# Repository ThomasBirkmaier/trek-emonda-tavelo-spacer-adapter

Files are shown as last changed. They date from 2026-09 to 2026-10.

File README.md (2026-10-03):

# Trek Émonda × Tavelo Avro Rise – Spacer-Adapter

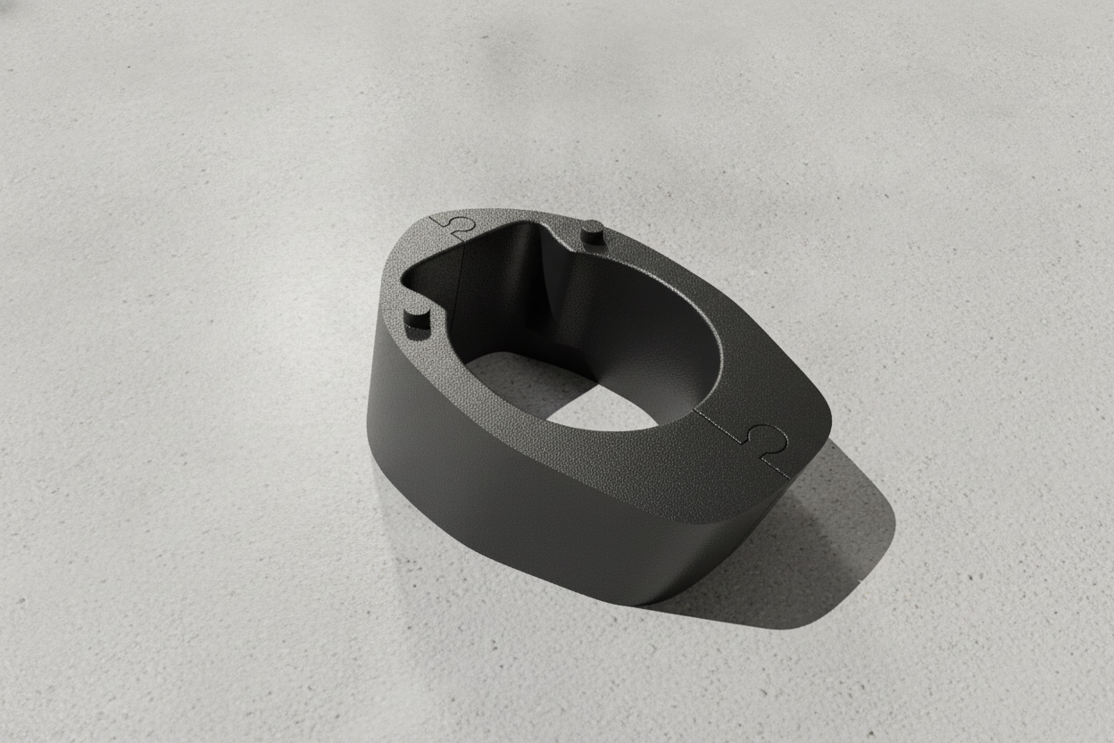
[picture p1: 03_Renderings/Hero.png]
Adapter, zusammengesetzt (generierte Darstellung, Variante Stift)


Zweiteiliger, 3D-gedruckter Adapter, mit dem ein integriertes **Tavelo Avro Rise**-Cockpit auf einem **Trek Émonda SL 6 (2024)** sitzt. Der originale Trek-Steuersatzdeckel bleibt unverändert, die Bremsleitungen laufen innen, und die Hydraulik muss nicht geöffnet werden.

Das Modell ist parametrisch (Python/CadQuery). Wer einen anderen Rahmen oder andere Winkel hat, ändert ein paar Zahlen und exportiert neu.

**Stand (Rev. D.1, 2026-10-03):** Geometrie abgeschlossen für die Bezugshöhe 22 mm (unverändert seit Rev. D), Festigkeit mit FEM abgeschätzt. Drei Prototypen wurden gedruckt und am Rad geprüft; der dritte (Variante Passstift, PETG-HF) passt ohne weitere Korrektur. Für den Dauerbetrieb empfohlen bleibt PA12 (MJF), siehe [Drucken](#drucken). Befunde, Entscheidungen und offene Punkte: [`KONSTRUKTION.md`](KONSTRUKTION.md).

## Für welches Rad und welches Cockpit

Konstruiert und vermessen an genau dieser Kombination:

| | |
|---|---|
| Rahmen | **Trek Émonda SL 6, Modelljahr 2024** (Gen-3-Plattform), 500 Series OCLV Carbon (**SL, nicht SLR**), Größe 54 |
| Artikel | GTIN/EAN 768682472743, Trek-Teilenr. 5297498 |
| Steuersatz | originaler Trek-Steuersatzdeckel mit zwei Nasen hinten, bleibt montiert |
| Gabelschaft | Carbon, Ø 28,6, seitlich abgeflacht auf 26,75 |
| Schaltung | **105 Di2** (funkend): durch den Adapter laufen nur zwei Bremsleitungen, keine Schaltzüge |
| Cockpit | **Tavelo Avro Rise**, 380 mm Breite, 80 mm Länge, −10° |

Nicht geprüft, aber naheliegend:
- **Andere Größen des Émonda SL:** Der Deckel ist vermutlich gleich, der Trek-Winkel kann aber vom Lenkwinkel der Größe abhängen (siehe [An ein anderes Rad anpassen](#an-ein-anderes-rad-anpassen)).
- **Andere Breiten und Längen des Avro Rise:** Die Sitzfläche des Vorbaus sollte gleich sein, das ist aber nicht nachgemessen.
- **Émonda SLR, ältere Modelljahre, andere Tavelo-Modelle, mechanische Schaltungen:** nicht kompatibel bzw. ungeprüft. Maße und Winkel stehen in [`KONSTRUKTION.md`](KONSTRUKTION.md), das Modell lässt sich anpassen.

## Variante wählen

Es gibt zwei Varianten. Sie sind bis auf die beiden Stifte oben, die in die Sacklöcher des Vorbaus greifen, identisch.

| | **Passstift** (empfohlen) | **Stift** |
|---|---|---|
| Stifte oben | Zylinderstifte aus Edelstahl, eingeklebt | angedruckt, Ø 3 × 1,85 |
| Am Rad geprüft | Prototyp 3 | Prototyp 1 und 2 (Stifte passten) |
| Druckdatei | [`02_CAD/out/Passstift/`](02_CAD/out/Passstift) | [`02_CAD/out/Stift/`](02_CAD/out/Stift) |
| Zusätzlich nötig | 2 × Zylinderstift ISO 2338 Ø 3 m6 × 8, Edelstahl A2/A4; Klebstoff (2K-Epoxid oder Cyanacrylat) | nichts |
| Eigenschaften | Stahlstift belastbarer als ein gedruckter; Stift sitzt auf dem Lochgrund, die Lochtiefe (6,15) legt den Überstand 1,85 fest | keine Zukaufteile; bei FDM liegt am Fuß des Stifts eine Schichtgrenze |

| Passstift | Stift |
|---|---|
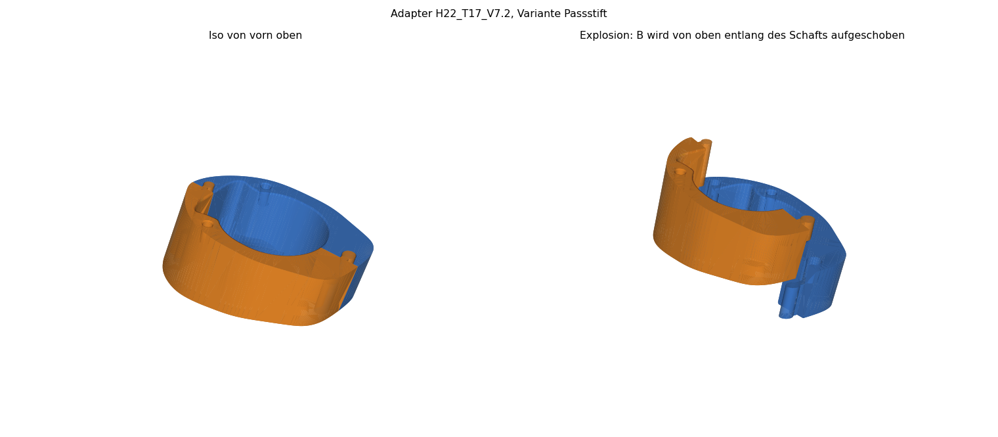
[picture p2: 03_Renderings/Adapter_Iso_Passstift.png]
Variante Passstift
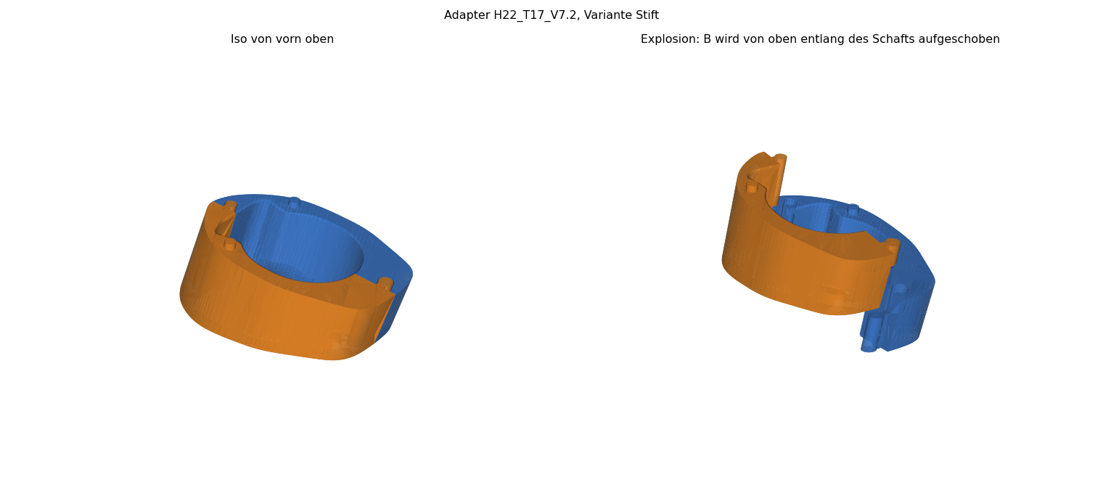
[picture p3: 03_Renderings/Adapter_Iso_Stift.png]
Variante Stift
|  |  |

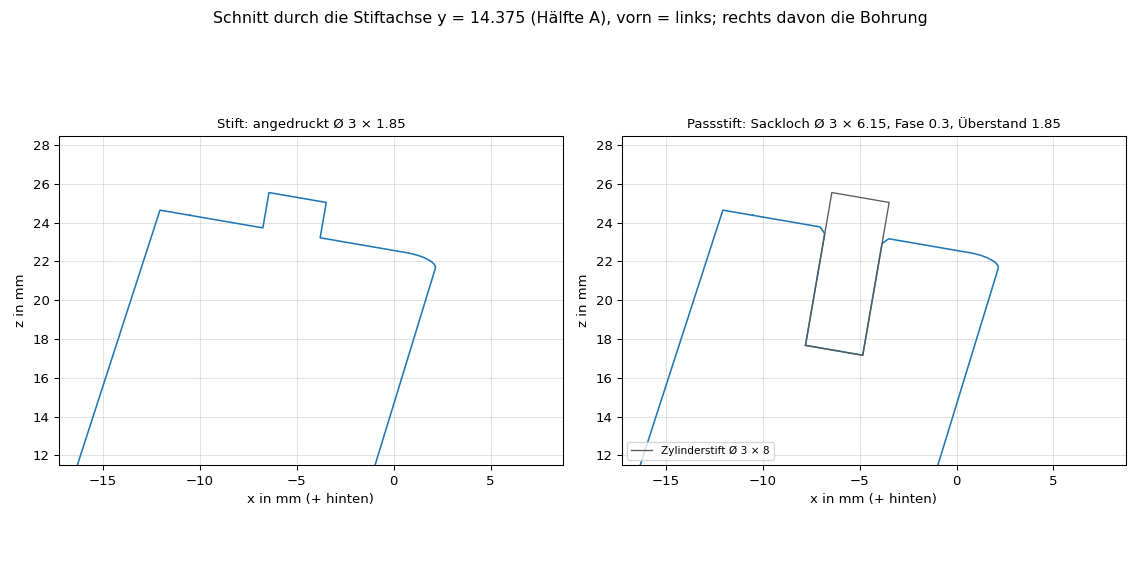
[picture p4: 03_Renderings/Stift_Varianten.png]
Schnitt durch die Stiftachse, beide Varianten


## Auf einen Blick

| | |
|---|---|
| Unterseite | passt auf den Trek-Deckel: Neigung α_T = 17°, zwei Nasen greifen in Taschen |
| Oberseite | passt unter den Tavelo-Vorbau: Neigung α_V ≈ 7,2° (gemessen 8°, am Prototyp 2 korrigiert), zwei Stifte Ø 3 × 1,85 greifen in die Sacklöcher |
| Keil | ≈ 9,8°, hinten dünn, vorn dick (auf einer ebenen Fläche: Hinterkante 16,3 mm, Spitze 26,2 mm hoch) |
| Höhe | 22 mm entlang der Schaftachse als Bezug (rechnerisch 22,4 mm am Durchstoßpunkt der Achse, siehe `KONSTRUKTION.md`, D-6) |
| Schaft | Ø 28,6 (seitlich abgeflacht auf 26,75), Bohrung Ø 30 als Langloch 2 mm nach hinten (32 × 30): Die Lage kommt von Nasen und Stiften, nicht vom Schaft |
| Leitungen | Kanal vor dem Schaft für zwei Bremsleitungen; unten seitlich angeschrägt, weil die hintere Leitung seitlich aus dem Trek-Deckel kommt |
| Teilung | zwei Hälften mit Gelenk nach Tavelo-Vorbild, werden entlang des Schafts zusammengeschoben |
| Kanten | innere Kanten an Ober- und Unterseite R 0,5, Übergang Bohrung → Leitungskanal R 2 |
| Werkstoff | empfohlen PA12, MJF-Druck; Prototyp 3 aus PETG-HF |
| Festigkeit | im Normalfall rund 4-fache Reserve in PETG-HF bei 3 kN entlang der Achse (lineare FEM-Abschätzung), siehe [Festigkeit](#festigkeit) |

## Festigkeit

Eine lineare FEM-Rechnung (gmsh + CalculiX, [`02_CAD/fem_adapter.py`](02_CAD/fem_adapter.py)) schätzt die Festigkeit unter einer Kraft von 3 kN entlang der Schaftachse ab. Das ist ein bewusst hoher Hüllwert; die Vorspannung allein liegt eher bei 0,3–1 kN.

- **Normalfall:** Reibung an Ober- und Unterseite hält den Keil. Größte Zugspannung 9 MPa, rund 4-fache Reserve in PETG-HF, knapp 6-fach in PA12; Verformung 0,06 mm.
- **Ohne Reibung** (gefettete Flächen) müssen Nasen oder Stifte die Keilkraft tragen, ≈ 17 % der Normalkraft. Dann werden Nasentasche und Lochmündung örtlich hoch belastet, und der angedruckte Stift der Variante Stift würde schon bei etwa 1 kN abscheren. Deshalb: Auflageflächen trocken und fettfrei, Variante Passstift.
- **Langzeit:** In PETG-HF kann der Spacer unter der Vorspannung bei Wärme kriechen; die Vorspannung lässt dann nach. Steuersatzspiel anfangs häufig prüfen, für den Dauerbetrieb PA12.

| Normalfall (Reibung trägt) | Grenzfall ohne Reibung, Passstift kippt im Vorbau |
|---|---|
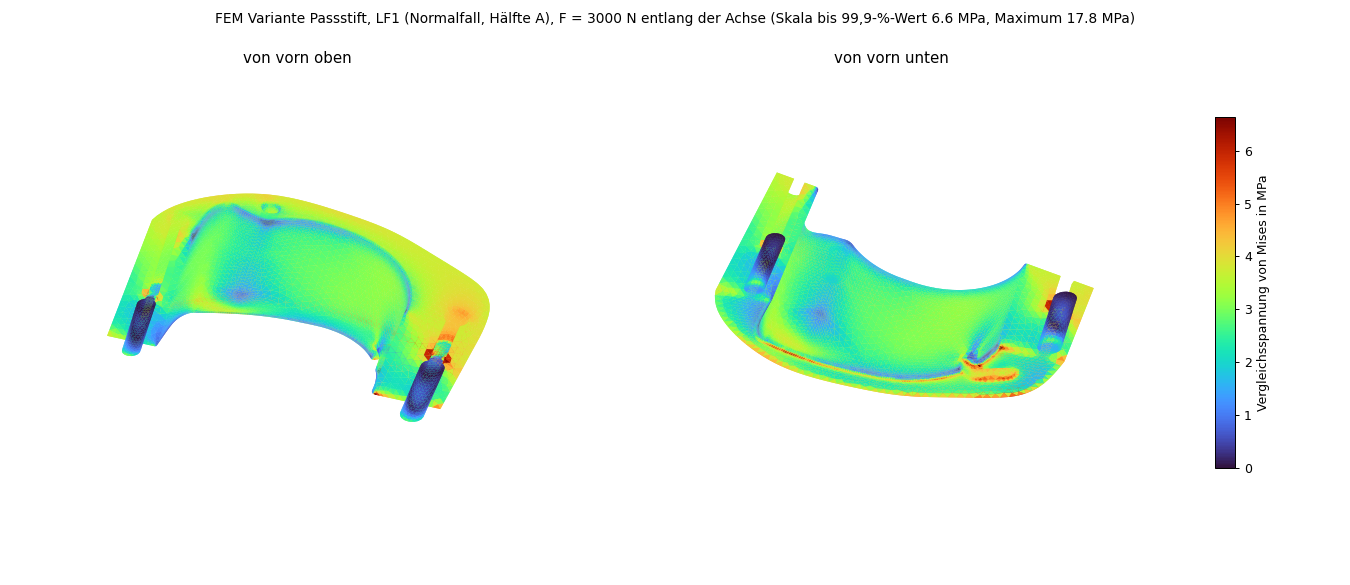
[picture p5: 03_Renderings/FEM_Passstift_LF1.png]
FEM Normalfall
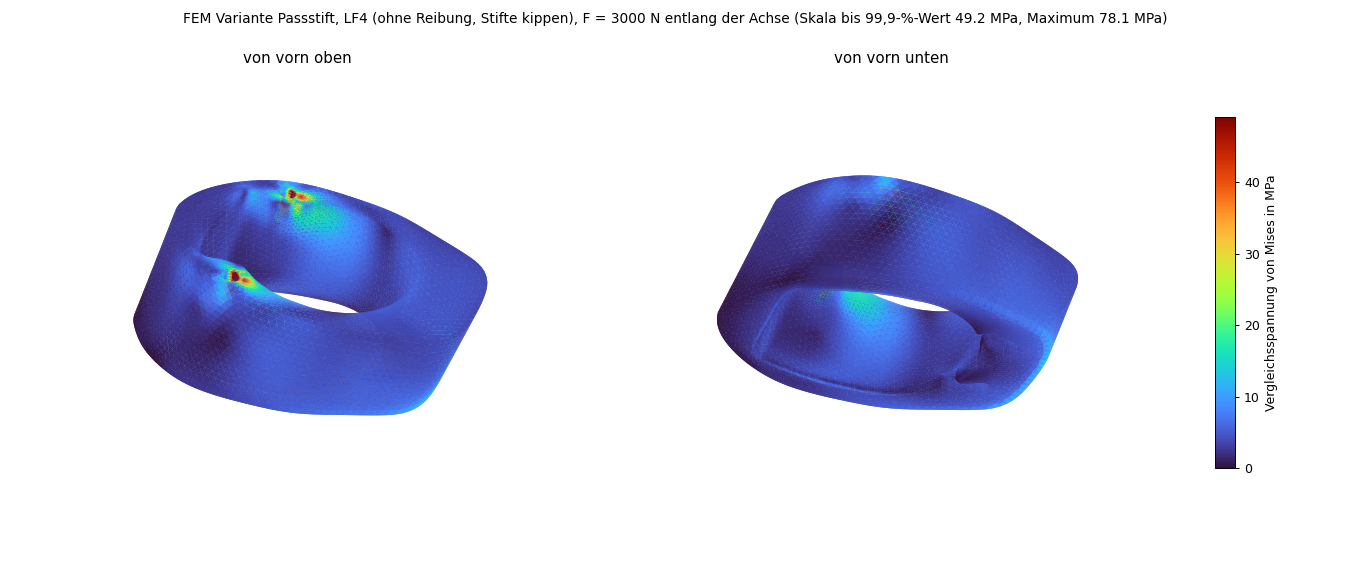
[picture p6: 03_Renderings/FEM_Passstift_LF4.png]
FEM ohne Reibung, Passstift
|  |  |

Das ist eine Abschätzung unter angenommenen Lasten, kein Festigkeitsnachweis. Modell, alle Lastfälle und Grenzen der Aussage: [`KONSTRUKTION.md`, Abschnitt 9](KONSTRUKTION.md#9-festigkeitsabschätzung-fem).

## Drucken

Am einfachsten lädt man unter [Releases](https://github.com/ThomasBirkmaier/trek-emonda-tavelo-spacer-adapter/releases) das ZIP der gewünschten Variante. Die Druckdatei `DRUCK_Adapter_H22_T17_V7.2_<Variante>` (`.stl`, `.3mf` oder `.step`) enthält beide Hälften, getrennt gelegt, Unterseite auf dem Druckbett. Bei einem Druckdienst (zum Beispiel Craftcloud) ist die Menge daher 1.

- **Verfahren und Werkstoff:** Für den Fahrbetrieb wird PA12 (MJF) empfohlen: Das Teil liegt in der Kraftkette der Lagervorspannung und wird warm. PETG (auch PETG-HF) kann unter dieser Last kriechen; wer es fährt, sollte das Steuersatzspiel anfangs häufig prüfen. Kein PLA. Für eine Passprobe reicht FDM.
- **Passungen:** Bohrung Ø 30 (0,7 mm Spiel radial zum Schaft, 2 mm Langloch nach hinten), Gelenk 0,2 mm Spiel radial, Nasentaschen 0,55 mm pro Seite quer und 0,3 mm längs, 3 mm tief. Sackloch der Variante Passstift Ø 3,0 × 6,15 mit Fase 0,3 (`PINHOLE_D` lässt sich an das Druckverfahren anpassen).
- **Dateinamen:** Bezugshöhe, Winkel und Variante stehen im Namen (`_H22_T17_V7.2_Passstift`). `Adapter_*` ist der zusammengebaute Zustand zur Ansicht, `DRUCK_*` die Druckdatei.

## Modell anpassen

Voraussetzung: Python 3.10–3.12 (getestet mit 3.11, Versionen in [`requirements.txt`](requirements.txt)).

```bash
git clone https://github.com/ThomasBirkmaier/trek-emonda-tavelo-spacer-adapter.git
cd trek-emonda-tavelo-spacer-adapter
python -m venv .venv && source .venv/bin/activate
pip install -r requirements.txt

python 02_CAD/adapter.py             # exportiert beide Varianten nach 02_CAD/out/Stift und 02_CAD/out/Passstift
python 02_CAD/check_adapter.py       # Kollision der Hälften, Bohrungsmaß, Wandstärken
python 02_CAD/render_adapter.py      # Schnitte, Iso-Ansichten, Drucklayout
python 02_CAD/check_exports.py       # passen die eingecheckten Exporte zum Code?
```

Optional die Festigkeitsabschätzung (Abschnitt 9 in `KONSTRUKTION.md`): zusätzlich `pip install gmsh` und CalculiX (`ccx`, unter Debian/Ubuntu `apt install calculix-ccx`), dann `python 02_CAD/fem_adapter.py` (mit dem Standardnetz rund 10 Minuten je Variante auf 2 Kernen).

Die Parameter stehen oben in [`02_CAD/adapter.py`](02_CAD/adapter.py):

| Parameter | Bedeutung | Aktuell |
|---|---|---|
| `ALPHA_TREK` | Neigung der Trek-Sitzfläche gegen die Schaftnormale | 17,0° (an den Prototypen bestätigt) |
| `ALPHA_TAVELO_MEAS`, `HEIGHT_REF` | gemessene Neigung der Tavelo-Sitzfläche, Bezugshöhe entlang der Schaftachse | 8,0°, 22 mm |
| `TOP_FRONT_LIFT` | Korrektur der Oberseite: um ihre Hinterkante gekippt, Spitze so viel höher; daraus ergeben sich `ALPHA_TAVELO` und `HEIGHT`. Der Vorbau sitzt dadurch nicht höher, nur der Spalt vorn wird gefüllt | 0,8 mm → 7,21°, 22,42 mm |
| `JOINT_CLEAR` | radiales Spiel im Gelenk | 0,2 mm |
| `BORE_D`, `BORE_SLOT` | Bohrungsdurchmesser, Langloch nach hinten | 30 mm (Schaft 28,6), 2 mm |
| `POCKET_CLEAR_W`, `POCKET_CLEAR`, `POCKET_DEPTH` | Nasentaschen: Spiel quer und längs pro Seite, Tiefe | 0,55 mm, 0,3 mm, 3 mm |
| `outline_wire_pts()`, `NOSE_*`, `PIN_*` | Kontur, Nasen, Stifte | laut Skizze V2 und Prototypen |
| `VARIANTS`, `DOWEL_L`, `PINHOLE_*` | Varianten; Länge des Zylinderstifts, Sackloch (Ø, Tiefe, Fase) | Ø 3 × 8; Loch Ø 3,0 × 6,15, Fase 0,3 |

### An ein anderes Rad anpassen

Die Stapelhöhe stellt man über `HEIGHT_REF` ein. Zwischen Schaftende und Oberkante Vorbau muss ein Spalt bleiben (üblich 2–3 mm), damit die Top-Cap Vorspannung aufbauen kann.

Die Winkel prüft man an einem Probedruck über die beiden Fugen:
- **Untere Fuge** (Trek-Deckel ↔ Adapter) klafft hinten: `ALPHA_TREK` zu groß; klafft sie vorn: zu klein. Über die Länge ergibt 1° etwa 1 mm Spalt.
- **Obere Fuge** (Adapter ↔ Vorbau) klafft vorn: den gemessenen Spalt zu `TOP_FRONT_LIFT` addieren; klafft sie hinten: abziehen.

## Repository-Struktur

| Pfad | Inhalt |
|---|---|
| [`KONSTRUKTION.md`](KONSTRUKTION.md) | Schnittstellen, Koordinatensystem, Maße, Winkel, Konstruktionsentscheidungen, Befund der Prototypen, offene Punkte, Revisionen |
| [`CLAUDE.md`](CLAUDE.md) | Einstieg für KI-Assistenten (Claude Code): Befehle und Fallstricke der Geometrie |
| `01_Input/` | Skizze, Herstellerzeichnung und Fotos, die ins Modell eingeflossen sind (Rohdaten; die Skizze nennt noch die Länge 52,2, richtig ist 58) |
| `02_CAD/adapter.py` | parametrisches Modell, einzige Quelle der Geometrie |
| `02_CAD/check_adapter.py`, `02_CAD/check_exports.py`, `02_CAD/render_adapter.py` | Prüfungen (Geometrie, Aktualität der Exporte) und Renderings |
| `02_CAD/fem_adapter.py` | Festigkeitsabschätzung (FEM, gmsh + CalculiX), Bilder `03_Renderings/FEM_*.png` |
| `02_CAD/out/Passstift/`, `02_CAD/out/Stift/` | Exporte je Variante: `DRUCK_*` druckfertig, `Adapter_*` zusammengebaut |
| `.github/workflows/release.yml` | legt bei einem Tag `rev-<Revision>` einen Release mit je einem ZIP pro Variante an |
| `03_Renderings/` | Aufmacherbild (generiert, ohne Maßbezug), sonst von `render_adapter.py` erzeugt: Schnitte, Iso-Ansicht je Variante, Schnitt durch die Stifte, Drucklayout |

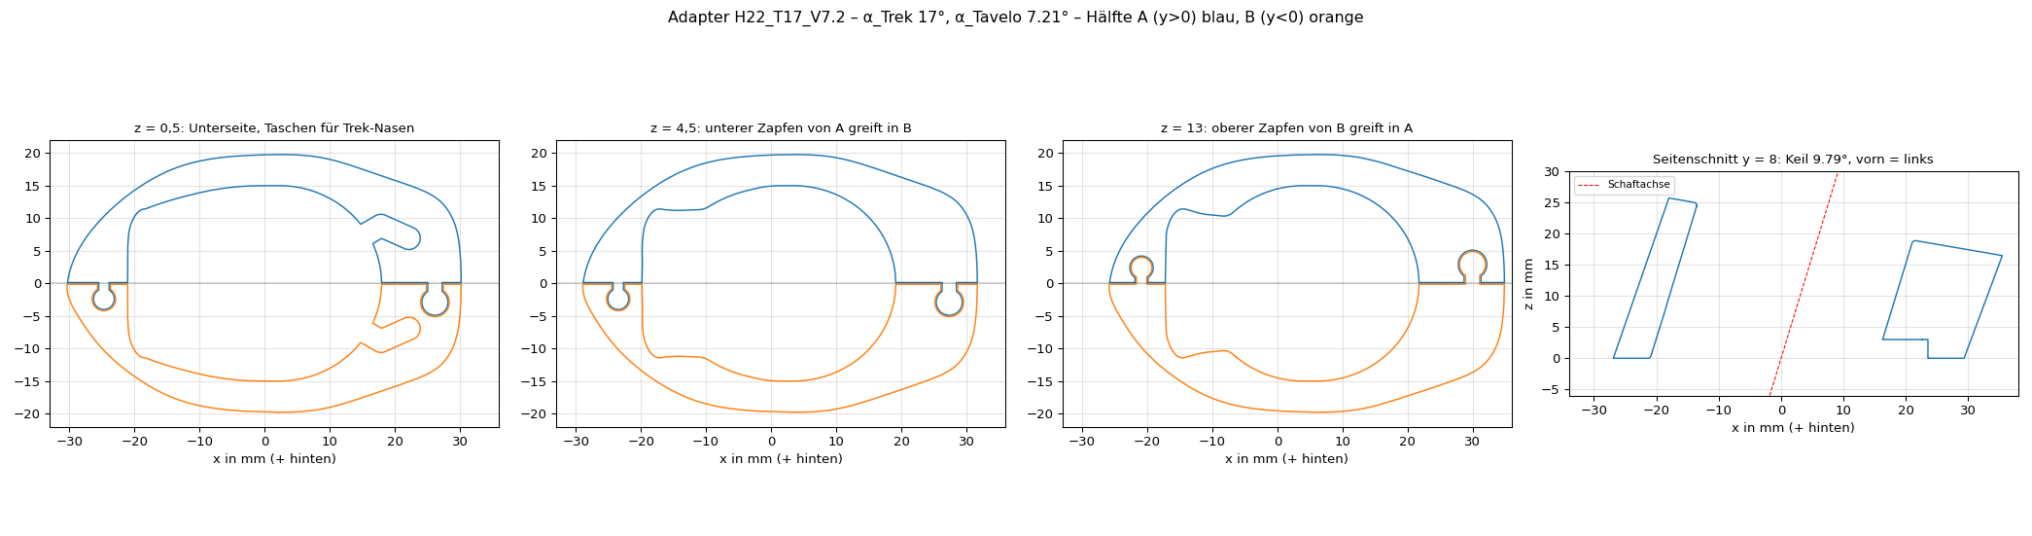
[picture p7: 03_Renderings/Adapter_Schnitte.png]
Schnitte


## Hinweis zur Sicherheit

Der Adapter sitzt am Steuersatz und damit an einem sicherheitsrelevanten Bauteil. Er ist ein privates Eigenbauprojekt ohne Herstellerfreigabe, ohne Festigkeitsnachweis (die FEM-Rechnung in `KONSTRUKTION.md`, Abschnitt 9, ist eine Abschätzung unter angenommenen Lasten) und ohne Langzeiterprobung. Die Auslegung setzt trockene, fettfreie Auflageflächen voraus. Maße und Winkel vor dem Druck am eigenen Rad prüfen; Steuersatz und Cockpit fachgerecht nach Herstellerangaben montieren. Nutzung auf eigene Verantwortung.

## Lizenz

[WTFPL](LICENSE): Jeder darf damit machen, was er will. Ohne jede Gewährleistung, siehe Hinweis zur Sicherheit.

Ausgenommen ist die Geometriezeichnung des Herstellers in `01_Input/Tavelo_Avro_Rise_Geometrie.png`; die Rechte daran liegen bei Tavelo. Marken- und Produktnamen gehören ihren Inhabern; das Projekt steht in keiner Verbindung zu Trek oder Tavelo.

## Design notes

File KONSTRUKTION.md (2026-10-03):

# Konstruktion

Adapter zwischen dem originalen Trek-Steuersatzdeckel (Émonda SL 6, 2024) und dem Tavelo-Avro-Rise-Cockpit.

**Stand:** Rev. D.1, 2026-10-03: Geometrie abgeschlossen für die Bezugshöhe 22 (unverändert seit Rev. D); Festigkeit mit FEM abgeschätzt (Abschnitt 9). Drei Prototypen gedruckt und am Rad geprüft (Abschnitt 6); Prototyp 3 (Variante Passstift) passt ohne weitere Korrektur. Zwei Varianten, die sich nur an den Stiften oben unterscheiden: **Passstift** (Sacklöcher für eingeklebte Zylinderstifte) und **Stift** (angedruckt), siehe D-12.

---

## 1. Schnittstellen

| ID | Schnittstelle | Gegenstück | Festlegung |
|---|---|---|---|
| IF-1 | Unterseite ↔ Trek-Deckel | originaler Trek-Deckel, bleibt unverändert | Kontur 60,5 × 39,5 (Spitze 2,5 weiter vorn als oben), zwei Nasen, Neigung α_T |
| IF-2 | Oberseite ↔ Tavelo-Vorbau | Vorbauunterseite (identisch zur Spacer-Sitzfläche) | Kontur 58 × 39,5, zwei Stifte in die Sacklöcher des Vorbaus (angedruckt oder als eingeklebte Zylinderstifte, D-12), Neigung α_V |
| IF-3 | Bohrung ↔ Gabelschaft | Carbonschaft Ø 28,6, seitlich abgeflacht auf 26,75 | Bohrung Ø 30 senkrecht zur Schaftachse, als Langloch 2 nach hinten verlängert (32 × 30), entlang der Schaftachse |
| IF-4 | Leitungsführung | 2 Bremsleitungen (Di2 funkt) | Tavelo-Kanal → Sichel → Öffnung im Trek-Deckel → Rahmen; die hintere Leitung kommt seitlich rechts aus dem Deckel (Leitungsschräge, D-11) |

## 2. Koordinatensystem

- **Ursprung:** Durchstoßpunkt der Schaftachse durch die Unterseite
- **x:** Längsachse, **+x nach hinten** (Richtung Oberrohr); Spitze vorn bei x = −28 (Oberseite) bzw. −30,5 (Unterseite)
- **y:** quer; Teilungsebene y = 0, Hälfte A bei y > 0, Hälfte B bei y < 0
- **z:** Normale der Unterseite
- **Schaftachse:** um α_T gegen z nach hinten geneigt

## 3. Maße (bemaßt; Skizze V2 plus Nachmessungen)

| Merkmal | Wert | Im Koordinatensystem |
|---|---|---|
| Kontur oben (Tavelo, in der Oberseite) | 58 × 39,5 | x = −28 … +30; y = ±19,75 |
| Kontur unten (Trek, in der Unterseite) | 60,5 × 39,5: vordere Hälfte nach vorn gestreckt, Spitze 2,5 weiter vorn; hintere Hälfte wie oben | x = −30,5 … +30 |
| Bohrungsmitte → Hinterkante | 30 | |
| vordere Bohrungskante → Spitze | 13,0 (Messmaß am Tavelo-Spacer, legt die Spitze fest) | |
| Sichel (Leitungskanal, zur Bohrung offen) | Vorderkante 6,8 hinter der Spitze; Breite außen 22,75 / innen 20,2 | x = −21,2; y = ±11,375 / ±10,1 |
| Stifte oben (Tavelo) | Ø 3 × 1,85; Abstand 28,75; 42,0 ab Hinterkante (Prototyp 1: 40,5, Adapter saß 1,5 zu weit vorn) | x = −12,0; y = ±14,375 (in der Oberseite) |
| Variante Passstift | Zylinderstift ISO 2338 Ø 3 m6 × 8, Edelstahl A2/A4, Überstand 1,85 (wie angedruckt), 6,15 im Loch; Sackloch Ø 3,0 × 6,15 ab Oberseite, Stift sitzt auf dem Grund, Fase 0,3 × 45° | gleiche Lage und Richtung wie die Stifte (senkrecht zur Oberseite) |
| Trek-Nasen | Langloch 7,6 × 2,4 × 1,5; äußerste Punkte 20,25 auseinander, innerste 11,35; Längsausdehnung 7,0 | Mitte x = +20,0; y = ±7,9; 24° zur Längsachse, V-förmig (vorn außen) |
| Taschen für die Nasen | Nase + 0,55 Spiel pro Seite quer (Breite 3,5) und 0,3 in Längsrichtung, Tiefe 3,0; vorderes (inneres) Ende zur Bohrung geöffnet (Durchbruch in Taschenbreite) | |
| Höhe | Bezug 22 entlang der Schaftachse (bis Prototyp 2: 20); rechnerisch 22,42 an der Achse durch die Keilkorrektur (D-6) | auf ebener Fläche gemessen: Hinterkante oben 16,3, Spitze oben 26,2 |

Die Skizze V2 in `01_Input/` nennt eine Gesamtlänge von 52,2; das war ein Messfehler, richtig sind 58 (13 + ~15 + 30).

Nasenwinkel abgeleitet: aus der Querausdehnung 23,2°, aus der Längsausdehnung 27,8°, beides erfüllt bei 24,0°. Die Maße sind auf ±0,2 konsistent; das Taschenspiel deckt die Unsicherheit ab.

## 4. Winkel und Keil

| Größe | Wert | Quelle |
|---|---|---|
| α_T: Trek-Sitzfläche gegen die Schaftnormale | **17°** | geschätzt (Trek-Stapel im Fahrbetrieb etwa waagerecht, Lenkwinkel ~73°), **an Prototyp 1 bis 3 bestätigt**: untere Fuge schließt |
| α_V: Tavelo-Sitzfläche gegen die Schaftnormale | **7,21°** (gemessen 8°, korrigiert) | gemessen: Klemmbohrung 8° nach hinten gekippt bei flach aufliegender Sitzfläche. Am Prototyp 2 klaffte oben vorn 0,8 zum Vorbau (Fühlerlehre, hinten dicht); die Oberseite ist deshalb um ihre Hinterkante gekippt, bis die Spitze 0,8 höher liegt (`TOP_FRONT_LIFT`): −0,79° |
| Keil zwischen Unter- und Oberseite | **α_T − α_V ≈ 9,8°** | hinten dünn, vorn dick |

Gegenprobe α_V (Stand vor der Korrektur nach Prototyp 2): Der Vorbau steht 80° zur Schaftachse und fällt damit relativ zur eigenen Sitzfläche um 2° ab. Am Émonda steigt die Sitzfläche 9° über die Horizontale, der Vorbau 7°. Das ist konsistent. Die gemessene „30-mm-Bohrung“ der Tavelo-Spacer ist Spiel (28,6 / cos 8° = 28,9). Der Adapter übernimmt die 30.

Der Lenkwinkel spielt für die Passung keine Rolle. Maßgeblich sind nur die Neigungen der Sitzflächen relativ zur Schaftachse.

## 5. Konstruktionsentscheidungen

| ID | Entscheidung | Begründung |
|---|---|---|
| D-1 | Bohrung Ø 30 senkrecht zur Schaftachse (0,7 Spiel radial zum Schaft Ø 28,6), als Langloch 2 nach hinten verlängert (32 × 30); Vorderkante 15 vor der Achse | Die Lage kommt von den Trek-Nasen unten und den Tavelo-Stiften oben, nicht vom Schaft. Das Langloch gibt dem Vorbau nach hinten Luft. Prototyp 1 (Ø 28,9, Kreise parallel zur Unterseite gezeichnet) war senkrecht zur Achse längs nur 27,6 und damit enger als der Schaft. Die Tavelo-Spacer haben ebenfalls 30. Wand zu den Stiften 1,6 (an der Kante R 0,5 oben; ohne Kantenradius 2,1), zu den Sacklöchern der Variante Passstift 1,3 (D-12). Die Nasentaschen sind zur Bohrung geöffnet (D-9). |
| D-2 | Außenwand = Regelfläche zwischen Trek-Kontur (unten) und Tavelo-Kontur (oben) | Beide Fugen schließen bündig, obwohl die Ebenen ≈ 10° gegeneinander stehen. |
| D-3 | Bohrung, Sichel und Gelenk entlang der Schaftachse | Das Teil wird entlang des Schafts gefügt, die Leitungen laufen parallel zum Schaft. Sichel und Gelenk sind als Profil parallel zur Unterseite definiert und entlang der Achse geschert, senkrecht zur Achse also längs um cos α_T kürzer; für sie ist das unerheblich. Die Bohrung ist ein echter Zylinder um die Achse (siehe D-1). |
| D-4 | Zweiteilig, Teilung bei y = 0 | Montage um Schaft und Leitungen, ohne die Hydraulik zu öffnen. |
| D-5 | **Gelenk nach Tavelo-Vorbild:** je Teilstelle zwei Zapfen mit Hals in Schlüssellochaufnahmen, unten von A nach B, oben von B nach A. Vorn: Ø 3,2 / Hals 1,6 / Versatz 2,4, bei x = −24,85 (Prototyp 1: −24,1; verschoben für mehr Wand zum Kanal). Kleinste Wand der vorderen Aufnahme zu Bohrung/Kanal 1,2 (oben, seit den Kantenradien D-10), unten 1,4. Hinten: Ø 4,0 / Hals 2,2 / Versatz 2,9, bei x = +26,0. Spiel 0,2 radial, 0,15 axial, Fuge 0,25 | Die Zapfen sperren quer. Gefügt wird durch Aufschieben von B entlang des Schafts. CAD-Kollisionstest: keine Überschneidung; quer blockiert ab ~0,5 mm; entlang des Schafts frei fügbar. |
| D-6 | Höhe 22 entlang der Schaftachse als Bezug (bis Prototyp 2: 20); durch die Korrektur der Oberseite (Kippen um die Hinterkante) liegt der Durchstoßpunkt der Achse bei 22,42 | ersetzt einen 20-mm-Spacerstapel und hebt den Vorbau um 2 mm: Der Schaft war so knapp gekürzt, dass die Top-Cap kaum Spalt für die Vorspannung hatte (O-8). Die 2 mm verschieben den Vorbau genau um 2,0 entlang der Achse (nachgerechnet); Winkel, Kontur, Stifte und Taschen bleiben. **Der Vorbau sitzt durch die Korrektur nicht höher:** Er lag am Prototyp 2 schon an der Hinterkante auf, und sein Winkel ist durch die Klemmung am Schaft fest; die Korrektur füllt nur den Spalt (vorher an der Spitze 0,80, an der Achse 0,41, an der Hinterkante 0). Nachgerechnet am Modell: Lage des Vorbaus alt ↔ neu entlang der Achse +0,0002 mm, neue Oberseite liegt auf 0,0000 mm in der Vorbau-Ebene. |
| D-7 | Werkstoff PA12 (MJF) für das Endteil empfohlen | Das Teil liegt in der Kraftkette der Lagervorspannung und wird warm. PETG (auch PETG-HF) kann unter dieser Last kriechen: dann lässt die Vorspannung nach, das Steuersatzspiel anfangs häufig prüfen. Kein PLA. |
| D-8 | Drucklayout: beide Hälften in einer Datei, getrennt, Unterseite auf dem Druckbett | ein Auftrag, keine verschränkten Teile im Druck |
| D-9 | Nasentaschen am vorderen (inneren) Ende zur Bohrung geöffnet: Durchbruch in Taschenbreite (3,5) Richtung Schaftachse, Tiefe wie die Tasche | Durch das Langloch bliebe nur ein Steg von 0,27, der beim Druck oder bei der Montage wegbricht. Offen gibt es keine losen Splitter; die Übergänge zur Bohrung sind stumpfwinklig. Die Nasen werden seitlich und am hinteren Ende geführt. |
| D-10 | Kantenradien: alle inneren Kanten an Ober- und Unterseite (Bohrung, Kanal, Übergang, Leitungsschräge) einheitlich R 0,5; der Übergang Langloch → Kanal entlang der Achse ist mit R 2,0 gerundet (als Teil des Schnitts, nicht als Verrundung) | Sauberes Aussehen, keine scharfen Kanten an den Leitungen. Einheitlich, weil die inneren Kanten tangential ineinander übergehen und sich so nur mit einem Radius verrunden lassen; R 1,0 würde die Wand zur oberen vorderen Gelenkaufnahme auf 0,64 senken (mit R 0,5: 1,21). Die R-2,0-Rundung ist im Schnitt konstruiert, damit die Leitungsschräge genau dieselbe Rundung trifft. |
| D-11 | Leitungsschräge an der Unterseite, beidseitig: Bogen R 45 (nach außen gewölbt) von der äußersten Ecke des Leitungskanals (x ≈ −18,5) zur breitesten Stelle des Langlochs (x = 0); das Material innerhalb fällt weg, bis zur halben Höhe der Schräge gerade, darüber läuft sie tangential (ohne Knick) in Kanal- und Bohrungswand aus, nach 10 mm entlang der Achse; Kante zur Unterseite R 0,5 | Die hintere Bremsleitung kommt seitlich rechts aus dem Trek-Deckel und bekommt so unten bis 3,4 mm mehr Luft. Oberseite unverändert. Außenwand an der Schräge min. ≈ 3,2 (Langloch sonst 4,74); die dünnsten Wände in diesem Bereich liegen weiterhin oben am Kanal (2,0) und an der vorderen Kanalecke (3,1) und werden nicht berührt. |
| D-12 | **Zwei Varianten**, sonst identisch (`VARIANTS`, ein gemeinsamer `core_body`): **Stift** mit angedruckten Stiften Ø 3 × 1,85; **Passstift** mit Sacklöchern Ø 3,0 × 6,15 (Fase 0,3) für Zylinderstifte ISO 2338 Ø 3 m6 × 8, Edelstahl, gleiche Lage und Richtung. Der Stift wird eingeklebt und sitzt auf dem Lochgrund: Die Lochtiefe legt den Überstand 1,85 fest | Stahlstifte sind belastbarer als angedruckte (bei FDM liegt am Fuß eine Schichtgrenze) und ergeben denselben Zapfen. Eingeklebt statt eingepresst: Ein Presssitz von 0,1 dehnt den Lochrand um ≈ 3 %, bei PETG im Bereich der Fließgrenze; die Wand zur Bohrung ist nur 1,3 bis 1,6. 8 mm Länge: 6,15 im Loch ≈ 2 × d reichen, der Stift trägt nur Querkräfte an der Oberseite; länger macht die Wand zur Bohrung dünner (10 mm: ≈ 1,46 statt 1,61 am Lochgrund). Wand Sackloch ↔ Bohrung 1,33 (nur oben an der Fase, darunter 1,6), ↔ Außenwand 1,77. Auf dem Grund statt mit Einstelllehre (Rev. C.6): kein Hilfsteil nötig. Der Überstand hängt dann an der Stiftlänge und an der Lage des gedruckten Lochgrunds (Schichthöhe, ≈ ±0,1–0,2); an Prototyp 3 passend. Ragt der Stift zu weit heraus, kann er in den (ungemessenen) Sacklöchern des Vorbaus aufsitzen. |

## 6. Befund der Prototypen

### Prototyp 1 (Rev. B.1, selbst gedruckt, am Rad anprobiert, 2026-09-29)

| Befund | Ursache | Änderung (Rev. C) |
|---|---|---|
| Winkel oben und unten passen, beide Fugen schließen (Prototyp 1 war nie vollständig montiert) | – | α_T = 17° und α_V = 8° vorerst bestätigt; α_V an Prototyp 2 korrigiert |
| Gelenk passt | – | vorderes Gelenk trotzdem 0,75 nach vorn (x = −24,85): Wand zum Leitungskanal 1,05 → 1,8 (später durch die Kantenradien 1,2, D-10) |
| Bohrung sehr schwer aufzuziehen, musste aufgefeilt werden | Kreise parallel zur Unterseite gezeichnet, senkrecht zur Achse längs nur 27,6 (Schaft 28,6) | Bohrung als echter Zylinder um die Achse, Ø 30, Langloch 2 nach hinten (D-1) |
| Adapter sitzt 1,5 zu weit vorn: steht vorn über den Vorbau, hinten fehlt Material | Stifte 1,5 zu weit hinten (Skizzenmaß 40,5 ab Hinterkante) | Stifte 42,0 ab Hinterkante (x = −12,0). Merkregel: Die Stifte sind im Vorbau fixiert; Stifte im Adapter nach vorn → Adapter wandert nach hinten |
| Seitlich kein Versatz | – | – |
| Taschen für die Trek-Nasen zu flach | – | Taschentiefe 1,8 → 2,5 |
| Untere Kante vorn muss weiter nach vorn | – | Unterseite vorn 2,5 länger (60,5); Oberseite exakt unverändert, weil dort der Vorbau passgenau aufliegt. Dadurch wird nur die Stirnwand vorn schräger |

### Prototyp 2 (Rev. C, FDM, 2026-10-01, montiert, Fühlerlehre)

| Befund | Ursache | Änderung |
|---|---|---|
| Oben vorn 0,8 Spalt zwischen Adapter und Vorbau, hinten dicht | Keil 0,79° zu flach (α_V-Messung) | Rev. C.2: Oberseite um ihre Hinterkante gekippt, Spitze 0,8 höher: α_V 7,21°, Keil 9,79°; der Spalt wird gefüllt, der Vorbau sitzt nicht höher (D-6) |
| Schaft so knapp gekürzt, dass die Top-Cap kaum Spalt für die Vorspannung hat; der Trek-Deckel ließ sich verdrehen | Schaftende zu hoch für 20 mm Stapel | Rev. C.3: Höhe 22 statt 20 (D-6) |
| Unten vorn dicht, hinten ein kurzer Abschnitt mit ≈ 0,15 Luft, danach dicht | örtlich, kein Winkelfehler | – |
| Hintere Unterkante schließt bündig mit dem Trek-Deckel | – | Unterseitenkontur nicht mehr ändern |
| Adapter setzt sich schwer bündig auf den Trek-Deckel | Nasentaschen knapp | Rev. C.4: Taschen 0,5 breiter, 3,0 tief |

### Prototyp 3 (Rev. C.6, Variante Passstift, PETG-HF, 2026-10-02, montiert)

| Befund | Ursache | Änderung |
|---|---|---|
| Passt: keine weitere Korrektur nötig | – | Rev. D: Geometrie wie C.6, Stand für die Bezugshöhe 22 abgeschlossen |

## 7. Offene Punkte

| ID | Punkt | Stand |
|---|---|---|
| O-1 | Wand zwischen Bohrungs-Langloch und Nasentaschen nur 0,27 | erledigt: Taschen zur Bohrung geöffnet (D-9) |
| O-2 | Feinschliff | erledigt: vorderes Gelenk verschoben (D-5), Taschen offen (D-9), Kantenradien (D-10) |
| O-3 | Prototyp 3 am Rad prüfen | erledigt: Variante Passstift passt (Abschnitt 6, Rev. D) |
| O-4 | Stahlstifte statt gedruckter Stifte | erledigt: Variante Passstift (D-12), eingeklebt statt eingepresst, weil ein Presssitz die Wand zur Bohrung (1,3 bis 1,6) überdehnen würde |
| O-5 | Idee: Einführfasen 0,3 an den angedruckten Stiften, 0,3–0,5 an den Enden der Gelenkzapfen | nicht umgesetzt; erleichtert das Fügen |
| O-6 | Idee: Gelenkspiel für MJF auf 0,25–0,3 (`JOINT_CLEAR`) | nicht umgesetzt; Einschätzung, kein Messwert. 0,2 hat im FDM-Prototyp gepasst |
| O-7 | Idee: „A“, „B“ und Revision innen einprägen; Oberfläche des Endteils gefärbt und dampfgeglättet | nicht umgesetzt |
| O-8 | Höhe 20 oder 22: Steht das Schaftende zu hoch, fehlt der Top-Cap der Spalt (Vorspannung) | erledigt: 22 (D-6, Rev. C.3) |
| O-9 | Teil in PA12 (MJF) oder gefräst | offen; das Teil in den finalen Maßen liegt in PETG-HF vor (Prototyp 3), die Geometrie von Rev. D gilt unverändert |
| O-10 | Andere Bezugshöhen (`HEIGHT_REF`) | nicht geprüft; abgeschlossen ist nur 22. Eine andere Höhe verschiebt den Vorbau entlang der Achse, Winkel und Kontur bleiben |
| O-11 | Langzeitverhalten in PETG-HF: Kriechen unter der Vorspannung, besonders bei Wärme (Abschnitt 9) | offen; Steuersatzspiel anfangs häufig prüfen |

Kräfte (FEM-Rechnung dazu in Abschnitt 9): Eine Kraft entlang der Schaftachse drückt den 9,79°-Keil mit ≈ 17 % der Normalkraft nach vorn (zum dicken Ende). Reibung an Ober- und Unterseite hält das zusammen schon ab μ ≈ 0,09 je Fläche; sonst tragen Nasen oder Stifte, und nach 2,7 (0,7 Spiel plus 2 Langloch) der Schaft. Flächenpressung bei 1 kN ≈ 1,2 MPa auf ≈ 405 mm² je Hälfte (≈ 810 mm² gesamt). Das Gelenk trägt keine Fahrlasten, jede Hälfte sitzt über eigene Nase und eigenen Stift. Lenk- und Biegemomente laufen über die Vorbauklemmung in den Schaft.

Prüfen nach jeder Änderung: `python 02_CAD/check_adapter.py` (Kollision der Hälften je Variante, Bohrungsmaß, Wandstärken).

## 8. Revisionen

| Rev. | Datum | Inhalt |
|---|---|---|
| B.1 | 2026-09-28 | α_V = 8° gemessen → Keil 9°; Höhe entlang der Schaftachse; Regelflächen-Außenwand; Drucklayout. Stand von Prototyp 1 |
| C | 2026-09-29 | Änderungen nach Prototyp 1 (Abschnitt 6); Taschen zur Bohrung geöffnet (D-9); Kantenradien (D-10) |
| C.1 | 2026-10-01 | Leitungsschräge an der Unterseite (D-11); Übergänge geglättet, Kantenradien einheitlich R 0,5 (D-10) |
| C.2 | 2026-10-01 | Keil nach Prototyp 2: Spitze oben 0,8 höher, α_V 7,21° (Spalt gefüllt, Vorbau unverändert) |
| C.3 | 2026-10-01 | Höhe 22 statt 20 (Spalt für die Top-Cap); Dateinamen `_H22_T17_V7.2` |
| C.4 | 2026-10-01 | Nasentaschen 0,5 breiter (Spiel quer 0,55 pro Seite) und 3,0 tief, damit der Adapter leichter bündig auf dem Trek-Deckel sitzt |
| C.5 | 2026-10-01 | Zweite Variante **Passstift** (Sacklöcher für eingeklebte Zylinderstifte, Lehre für den Überstand), sonst identisch mit **Stift** (D-12); Dateinamen mit Variante `_H22_T17_V7.2_Stift` / `_Passstift` |
| C.6 | 2026-10-01 | Passstift sitzt auf dem Grund: Sackloch 6,15 statt 7,15 tief, Lehre entfällt (D-12); je Variante ein Ordner in `02_CAD/out/` |
| D | 2026-10-02 | Prototyp 3 (Variante Passstift) passt: Geometrie unverändert wie C.6, Stand für die Bezugshöhe 22 abgeschlossen; Dokumentation für die Veröffentlichung überarbeitet, Fotos in `01_Input/` als JPEG |
| D.1 | 2026-10-03 | Festigkeitsabschätzung mit FEM (Abschnitt 9, `02_CAD/fem_adapter.py`): im Normalfall ausreichend fest, Voraussetzung trockene Auflageflächen, Variante Passstift bestätigt; Geometrie unverändert wie D |

## 9. Festigkeitsabschätzung (FEM)

Lineare FEM-Rechnung mit gmsh (quadratische Tetraeder C3D10) und CalculiX, Skript `02_CAD/fem_adapter.py`, Bilder `03_Renderings/FEM_*.png`. Das ist eine Plausibilisierung unter angenommenen Lasten, kein Festigkeitsnachweis.

**Mechanik.** Der Adapter ist ein Keil (9,79°) zwischen Vorbau und Trek-Deckel. Eine Kraft F entlang der Schaftachse drückt ihn mit ≈ 17 % der Normalkraft nach vorn, zum dicken Ende. Reibung oben und unten hält das zusammen schon ab μ ≈ 0,09 je Fläche; dann tragen Nasen und Stifte nichts. Ohne Reibung trägt entweder die Nase (am Trek-Deckel) oder der Stift (im Vorbau) die Keilkraft, je nachdem, wo das Spiel zuerst aufgebraucht ist (Nase 0,3 längs; Stift im Vorbau ungemessen). Der Schaft liegt in Schubrichtung erst nach 2,7 an (0,7 Spiel plus 2 Langloch).

**Modell**
- Last: **F = 3 kN** entlang der Achse als bewusst hoher Hüllwert (Vorspannung der Top-Cap plus Zusatzlast im Fahrbetrieb, wenn der Rahmen gegenüber der Gabel nach oben drückt; für Spacer gibt es keine Norm). Die Vorspannung allein liegt eher bei 0,3–1 kN (Annahme). Linear: Spannungen skalieren mit F.
- LF1 an Hälfte A: Die Hälften sind durch die Fuge getrennt und tragen je F/2 über ihre Flächen. LF2 bis LF4 am ganzen Ring, weil die Gelenke die Hälften quer koppeln; hier vereinfacht als starre Verbindung.
- Werkstoff isotrop linear-elastisch. **PETG-HF** (Bambu PETG HF TDS V1.0, 100 % Füllgrad, getempert): E 1810 / 1540 MPa, Zugfestigkeit 34 MPa in der Schicht, 23 MPa quer zu den Schichten, HDT 62 °C bei 1,8 MPa, Tg 66 °C. **PA12 MJF** (HP 3D HR PA12): E 1750 / 1950 MPa, Zugfestigkeit 50 / 51 MPa, HDT 104–108 °C bei 1,82 MPa. Druckrichtung Unterseite auf dem Bett: Die Schichten liegen parallel zur Unterseite, σ_zz ist die Spannung quer zu den Schichten.
- Netz 1,5 mm (0,4 an Rundungen), Hälfte ≈ 89 000, Ring ≈ 195 000 Knoten; quadratische Elemente mit geraden Kanten. Gegen 2,0 mm und (für LF1) 1,0 mm ändern sich Verschiebungen und 99,9-%-Werte um < 10 %. Stabil sind auch die Spitzen am Sackloch in LF4 (82,7 → 81,3 MPa); die Spitzen in LF2 und LF3 sitzen am Rand der Lagerung und werden über Nennwerte bewertet.
- Gegenproben: Reaktionskräfte = Last (LF1 438,6 / 0 / 1434,5 N = 1500 N · (sin 17°, 0, cos 17°); LF2/LF3 514 / 0 / 2980 N = N · (sin 9,79°, 0, cos 9,79°); LF4 quer 0, wie bei statisch bestimmter Lagerung gewollt). Mittlere Pressung oben 3,7 MPa bei 3 kN (≈ 405 mm² je Hälfte). Stiftfuß nach Biegeformel und FEM in derselben Größenordnung.

**Lastfälle und Ergebnisse** (F = 3 kN; bei 1 kN alle Spannungen durch 3)

| Lastfall | Annahme | maßgebender Wert | Ort | Sicherheit PETG-HF (in der Schicht / quer) | Sicherheit PA12 |
|---|---|---|---|---|---|
| LF1 Normalfall | Reibung trägt: Unterseite fest, Last entlang der Achse (verlangt unten μ ≈ 0,31, also konservativ) | σ1 8,8 MPa, σ_zz 2,9 MPa, Verformung 0,06 mm | Ecke der hinteren Gelenkaufnahme, Taschenrand | 3,9 / 7,9 | 5,7 |
| LF2 ohne Reibung, Nasen | Keilkraft 261 N je Seite an der hinteren Taschenstirn (Kontakt auf Nasenhöhe 1,5) | Pressung an der Nasenstirn nominell 72 MPa (FEM am Kontaktrand σ1 69, σ3 −80 MPa) | Nasentasche | bei 3 kN überlastet; bei 1 kN Pressung 24 MPa | bei 1 kN ≈ 2 |
| LF3 ohne Reibung, Passstift eingespannt | Stift im Vorbau fest, Lochwand unterhalb der Fase gehalten | σ1 22 MPa | Lochgrund | 1,6 / 3,6 | 2,3 |
| LF4 ohne Reibung, Passstift kippt | Querkraft 261 N je Stift in halber Überstandshöhe, Lagerdruck an der Mündung am größten | σ1 81 MPa, σ_zz 17 MPa | Lochflanke zur Bohrung (Wand 1,3) | 0,42 / 1,4 (bei 1 kN: 1,3 / 4,1) | 0,62 (bei 1 kN: 1,8) |
| LF3 Variante Stift | angedruckter Stift im Vorbau gehalten | σ1 97 MPa; nominell Schub im Fuß 37 MPa, bei kippendem Stift Biegung 91 MPa | Stiftfuß, in der Schichtebene | 0,35 (bei 1 kN: 1,05) | 0,52 (bei 1 kN: 1,6) |

**Bewertung**
- **Normalfall:** Unter Druck über die Flächen ist der Adapter unkritisch. Selbst bei 3 kN liegt die größte Zugspannung bei 9 MPa: rund 4-fache Reserve in PETG-HF (quer zu den Schichten fast 8-fach), knapp 6-fach in PA12. Die Verformung (0,06 mm) ist vernachlässigbar.
- **Voraussetzung sind trockene, fettfreie Auflageflächen.** Nur dann hält die Reibung die Keilkraft. Ohne Reibung trägt die Nase sie mit hoher Pressung an der Taschenstirn: Bei 3 kN wird die Stirn örtlich eingedrückt, bei der Vorspannung allein (≤ 1 kN, 24 MPa) bleibt es elastisch, kann in PETG aber kriechen; der Adapter würde sich dann um das Taschenspiel nach vorn setzen.
- **Passstift:** Ist der Stift im Vorbau eingespannt, ist das Sackloch unkritisch. Kann er kippen, konzentriert sich der Lagerdruck an der Lochmündung zur Bohrung hin (Wand 1,3): Bei 1 kN bleibt in PETG-HF nur 1,3-fache Reserve, bei 3 kN wird der Lochrand örtlich überlastet (er weitet sich, der Stift bleibt vom Vorbau gehalten). Das ist nur relevant, wenn die Reibung fehlt.
- **Angedruckter Stift:** Ohne Reibung würde er schon bei etwa 1 kN im Fuß abscheren oder abbrechen, und zwar in der Schichtgrenze (Schub 12 MPa, Biegung 30 MPa bei 1 kN gegen 23 MPa quer zu den Schichten). Das bestätigt D-12: Variante Passstift empfohlen.
- **Kriechen (nicht gerechnet, Abschätzung):** Die Vorspannung wirkt dauerhaft, die mittlere Pressung liegt bei 1 kN bei ≈ 1,2 MPa. PETG-HF hat seine Wärmeformbeständigkeit bei 62 °C und den Glasübergang bei 66 °C; ein schwarzes Teil in der Sonne kann 50–60 °C erreichen (Annahme). Dann kriecht PETG merklich, und die **Vorspannung lässt nach** (Steuersatzspiel), ohne dass das Teil bricht. Bei 1 kN wird der Spacer axial nur ≈ 0,015 mm zusammengedrückt (F · h / (E · A)); ist er das weichste Glied im verspannten Stapel (Annahme; ≈ 65 kN/mm, der Carbonschaft liegt vermutlich in ähnlicher Größenordnung), kann schon Kriechen von wenigen Tausendstelmillimetern einen spürbaren Teil der Vorspannung kosten. PA12 (HDT > 100 °C) ist hier deutlich unkritischer.

**Grenzen der Aussage:** linear-elastisch, isotrop, ohne Kontakt, ohne Reibung im Modell und ohne Kriechen; Kurzzeitfestigkeit der Datenblätter (ideale Probekörper; reale Drucke, besonders zwischen den Schichten, oft schwächer); der Vorbau drückt als gleichmäßige Flächenlast, nicht als steifer Körper; keine Ermüdung, kein Schlag; Lasten angenommen, nicht gemessen.

**Folgerung:** Im Normalfall ausreichend fest, auch in PETG-HF. Entscheidend sind trockene Auflageflächen und die Variante Passstift. In PETG-HF ist das Langzeitrisiko das Nachlassen der Vorspannung durch Kriechen; deshalb das Steuersatzspiel anfangs häufig prüfen, für den Dauerbetrieb PA12.

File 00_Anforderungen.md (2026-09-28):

# Anforderungen und Konstruktionsstand

Adapter zwischen dem originalen Trek-Steuersatzdeckel (Émonda SL 6, 2024) und dem Tavelo-Avro-Rise-Cockpit.

**Stand:** 2026-09-28 · Rev. B.1 · finaler Prototyp in Fertigung

---

## 1. Schnittstellen

| ID | Schnittstelle | Gegenstück | Festlegung |
|---|---|---|---|
| IF-1 | Unterseite ↔ Trek-Deckel | originaler Trek-Deckel, bleibt unverändert | Kontur 58 × 39,5, zwei Nasen, Neigung α_T |
| IF-2 | Oberseite ↔ Tavelo-Vorbau | Vorbauunterseite (identisch zur Spacer-Sitzfläche) | Kontur 58 × 39,5, zwei Stifte in die Sacklöcher des Vorbaus, Neigung α_V |
| IF-3 | Bohrung ↔ Gabelschaft | Carbonschaft Ø 28,6, seitlich abgeflacht auf 26,75 | Bohrung Ø 28,9, rund, entlang der Schaftachse |
| IF-4 | Leitungsführung | 2 Bremsleitungen (Di2 funkt) | Tavelo-Kanal → Sichel → Öffnung im Trek-Deckel → Rahmen |

## 2. Koordinatensystem

- **Ursprung:** Durchstoßpunkt der Schaftachse durch die Unterseite
- **x:** Längsachse, **+x nach hinten** (Richtung Oberrohr), Spitze vorn bei x = −28
- **y:** quer; Teilungsebene y = 0, Hälfte A bei y > 0, Hälfte B bei y < 0
- **z:** Normale der Unterseite
- **Schaftachse:** um α_T gegen z nach hinten geneigt

## 3. Maße (bemaßt; Skizze V2 plus Nachmessungen)

| Merkmal | Wert | Im Koordinatensystem |
|---|---|---|
| Kontur (unten Trek, oben Tavelo, jeweils in der eigenen Ebene) | 58 × 39,5 | x = −28 … +30; y = ±19,75 |
| Bohrungsmitte → Hinterkante | 30 | |
| vordere Bohrungskante → Spitze | 13,0 | |
| Sichel (Leitungskanal, zur Bohrung offen) | Vorderkante 6,8 hinter der Spitze; Breite außen 22,75 / innen 20,2 | x = −21,2; y = ±11,375 / ±10,1 |
| Stifte oben (Tavelo) | Ø 3 × 1,85; Abstand 28,75; 40,5 ab Hinterkante | x = −10,5; y = ±14,375 (in der Oberseite) |
| Trek-Nasen | Langloch 7,6 × 2,4 × 1,5; äußerste Punkte 20,25 auseinander, innerste 11,35; Längsausdehnung 7,0 | Mitte x = +20,0; y = ±7,9; 24° zur Längsachse, V-förmig (vorn außen) |
| Taschen für die Nasen | Nase + 0,3 Spiel pro Seite, Tiefe 1,8 | |
| Höhe | 20 entlang der Schaftachse | senkrecht zur Unterseite: hinten 15,5 / Achse 20,1 / vorn 24,3 |

Nasenwinkel abgeleitet: aus der Querausdehnung 23,2°, aus der Längsausdehnung 27,8°, beides erfüllt bei 24,0°. Die Maße sind auf ±0,2 konsistent; das Taschenspiel deckt die Unsicherheit ab.

## 4. Winkel und Keil

| Größe | Wert | Quelle |
|---|---|---|
| α_T: Trek-Sitzfläche gegen die Schaftnormale | **17°** (vorläufig) | Trek-Stapel im Fahrbetrieb etwa waagerecht, Lenkwinkel ~73°; **Lehrkeile 15–19° klären den exakten Wert** |
| α_V: Tavelo-Sitzfläche gegen die Schaftnormale | **8°** | gemessen: Klemmbohrung 8° nach hinten gekippt bei flach aufliegender Sitzfläche |
| Keil zwischen Unter- und Oberseite | **α_T − α_V ≈ 9°** | hinten dünn, vorn dick |

Gegenprobe α_V: Der Vorbau steht 80° zur Schaftachse und fällt damit relativ zur eigenen Sitzfläche um 2° ab. Am Émonda steigt die Sitzfläche 9° über die Horizontale, der Vorbau 7°. Das ist konsistent. Die gemessene „30-mm-Bohrung" der Tavelo-Spacer ist Spiel (28,6 / cos 8° = 28,9).

Der Lenkwinkel spielt für die Passung keine Rolle. Maßgeblich sind nur die Neigungen der Sitzflächen relativ zur Schaftachse.

## 5. Konstruktionsentscheidungen

| ID | Entscheidung | Begründung |
|---|---|---|
| D-1 | Bohrung Ø 28,9 (28,6 + 0,15 radial), rund, entlang der Schaftachse | Das Teil zentriert sich auf dem Schaft, die Nasen richten es aus. Es klemmt nicht; die Vorbauklemmung (gemessen 28,5) ist ohne Belang. |
| D-2 | Außenwand = Regelfläche zwischen Trek-Kontur (unten) und Tavelo-Kontur (oben) | Beide Fugen schließen bündig, obwohl die Ebenen 9° gegeneinander stehen. |
| D-3 | Bohrung, Sichel und Gelenk entlang der Schaftachse | Das Teil wird entlang des Schafts gefügt, die Leitungen laufen parallel zum Schaft. |
| D-4 | Zweiteilig, Teilung bei y = 0 | Montage um Schaft und Leitungen, ohne die Hydraulik zu öffnen. |
| D-5 | **Gelenk nach Tavelo-Vorbild:** je Teilstelle zwei Zapfen mit Hals in Schlüssellochaufnahmen, unten von A nach B, oben von B nach A. Vorn: Ø 3,2 / Hals 1,6 / Versatz 2,4, bei x = −24,1. Hinten: Ø 4,0 / Hals 2,2 / Versatz 2,9, bei x = +26,0. Spiel 0,2 radial, 0,15 axial, Fuge 0,25 | Die Zapfen sperren quer. Gefügt wird durch Aufschieben von B entlang des Schafts. CAD-Kollisionstest: keine Überschneidung; quer blockiert ab ~0,5 mm; entlang des Schafts frei fügbar. |
| D-6 | Höhe 20 entlang der Schaftachse | ersetzt einen 20-mm-Spacerstapel |
| D-7 | Werkstoff PA12 (MJF) für das Endteil | Das Teil liegt in der Kraftkette der Lagervorspannung und wird warm; kein PLA/PETG. |
| D-8 | Lehrkeile: 4 mm, Vollkontur, zweiteilig ohne Gelenk, Ober- und Unterseite parallel | Sie prüfen nur α_T; ein Gelenk wäre bei 4 mm zu filigran. |
| D-9 | Drucklayout: beide Hälften in einer Datei, getrennt, Unterseite auf dem Druckbett | ein Auftrag, keine verschränkten Teile im Druck |

## 6. Offene Punkte

| ID | Frage | Vorgehen |
|---|---|---|
| O-1 | Exakter Wert von α_T | Lehrkeile drucken und prüfen (`04_Fertigung/Lehrkeile_Auftrag.md`). Weicht der Wert von 17° ab: `ALPHA_TREK` in `02_CAD/adapter.py` ändern und neu exportieren. |
| O-2 | Passung des Gelenks nach MJF-Druck | Testmontage; bei Bedarf Zapfen nachschleifen oder `JOINT_CLEAR` auf 0,3 erhöhen. |

## 7. Verworfene Annahmen (Kurzfassung)

- **Gesamtlänge 52,2** (Skizze V2) war ein Messfehler, richtig sind **58** (13 + ~15 + 30).
- **Oberseite senkrecht zum Schaft** (Keil 17°), abgeleitet aus der Stack-Bemaßung der Tavelo-Zeichnung: durch die Messung α_V = 8° widerlegt.
- **α_V = 18°** (Keil ≈ 0°), abgeleitet aus der Tavelo-Referenz 72°: durch die Messung widerlegt.
- **Z-Schloss** als Teilung: hält die Hälften quer nicht; ersetzt durch das Gelenk (D-5).
- **Lehrkeil vorn offen:** ersetzt durch die zweiteilige Vollkontur.

## 8. Revisionen

| Rev. | Inhalt |
|---|---|
| A–A.3 | Anforderungen aus Skizze V2 und Fotos, Lehrkeil-Ansatz, Maßkorrekturen |
| B.0 | Adapter 20 mm mit Gelenk nach Tavelo-Vorbild |
| B.1 | α_V = 8° gemessen → Keil 9°; Höhe entlang der Schaftachse; Regelflächen-Außenwand; Drucklayout |

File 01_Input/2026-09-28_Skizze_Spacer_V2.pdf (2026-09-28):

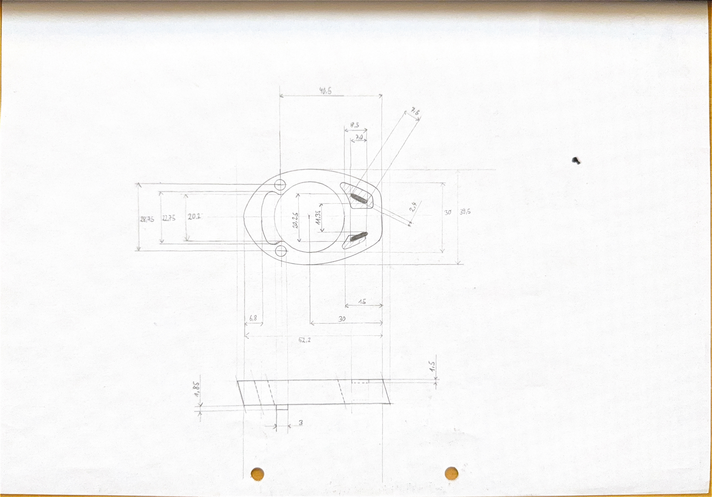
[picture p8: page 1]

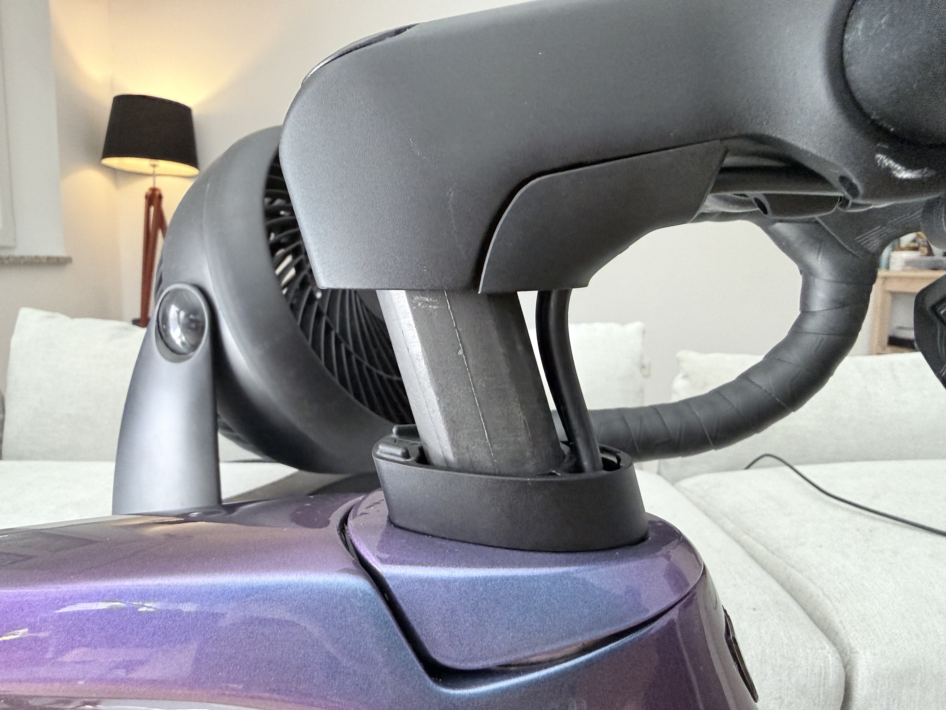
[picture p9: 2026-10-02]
01_Input/2026-09-28_Trek-Vorbau_angehoben_seitlich_1.jpg

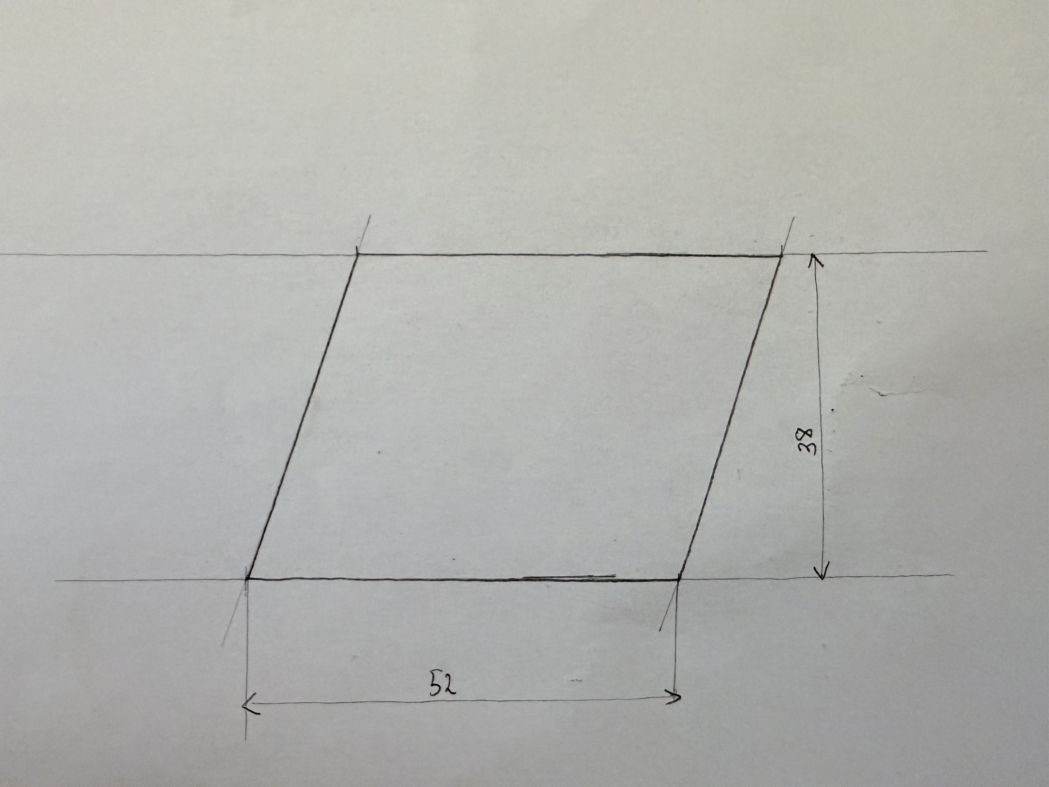
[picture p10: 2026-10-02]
01_Input/2026-09-28_Skizze_Trek-Spacer_Schraege_52x38.jpg

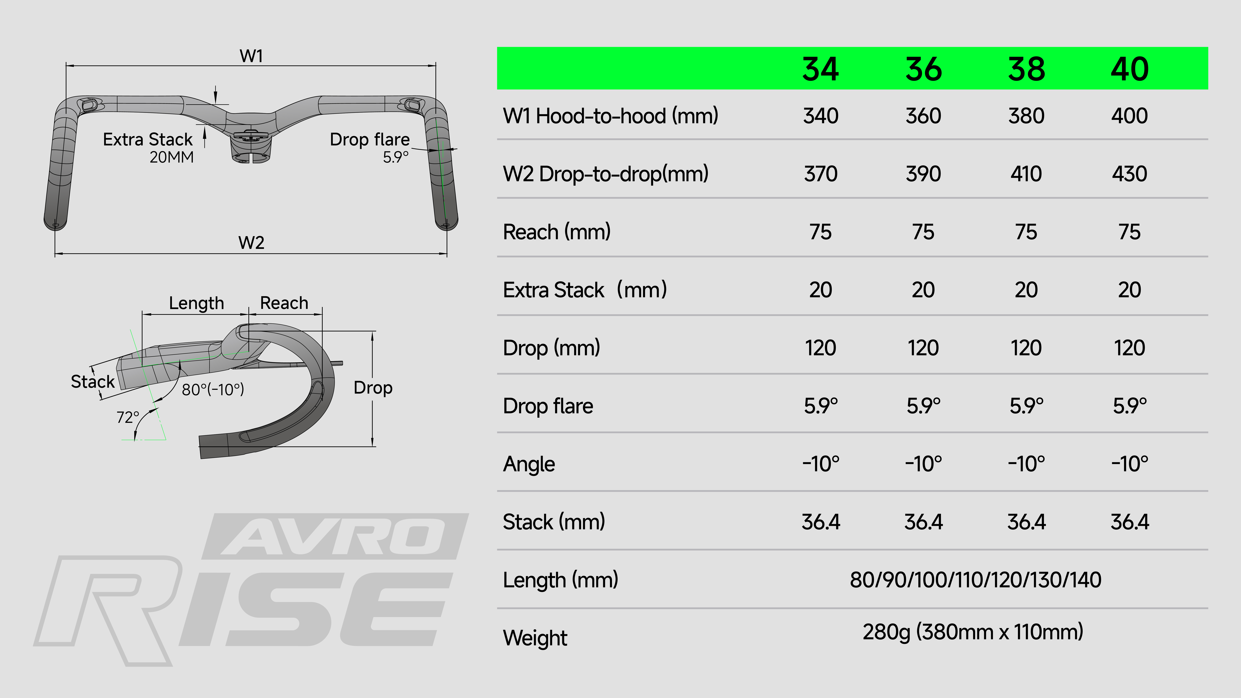
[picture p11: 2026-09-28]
01_Input/Tavelo_Avro_Rise_Geometrie.png

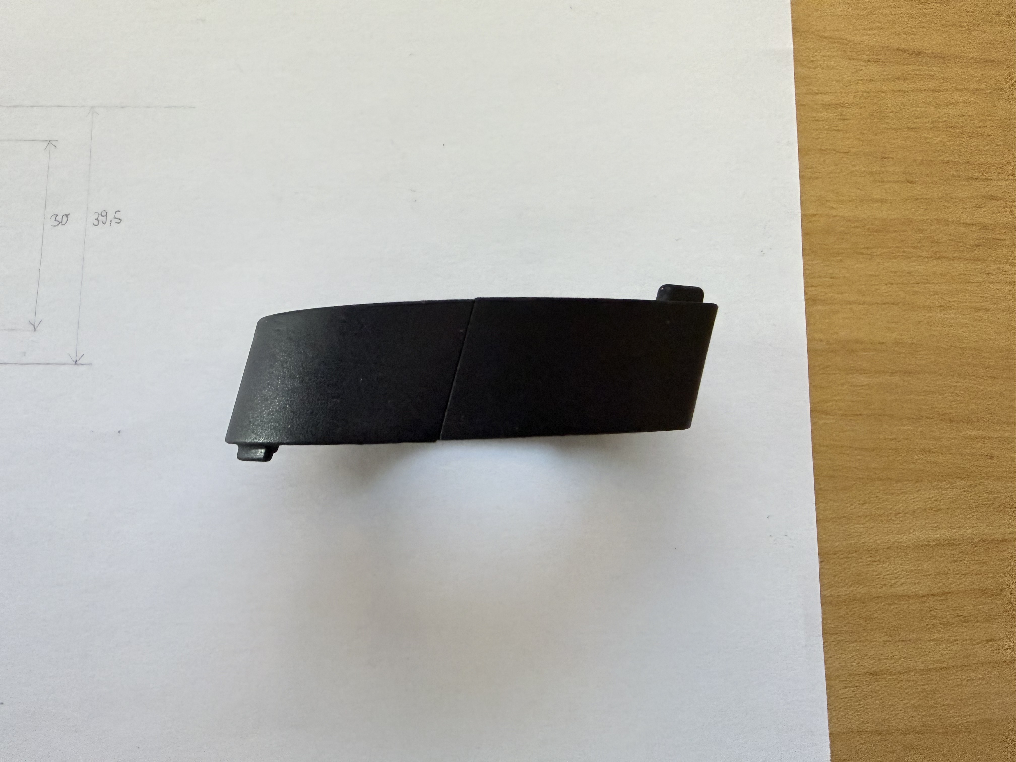
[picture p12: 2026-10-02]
01_Input/2026-09-28_Trek-Spacer_seitlich.jpg

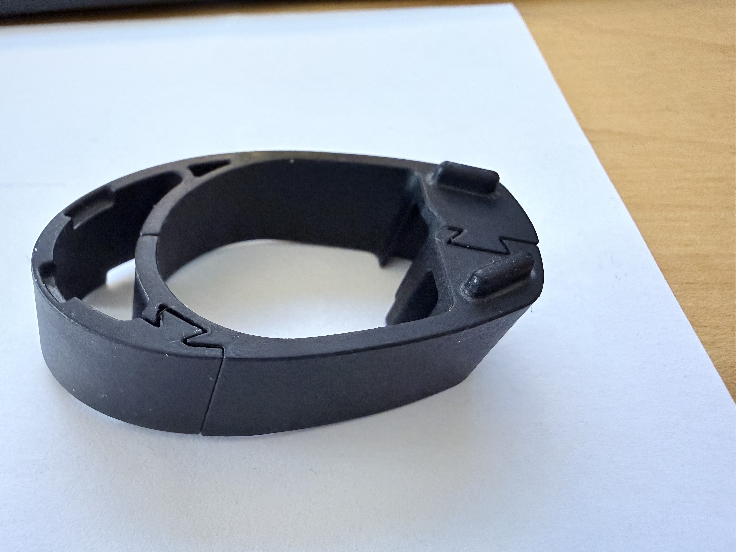
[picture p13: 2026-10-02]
01_Input/2026-09-28_Trek-Spacer_schraeg.jpg

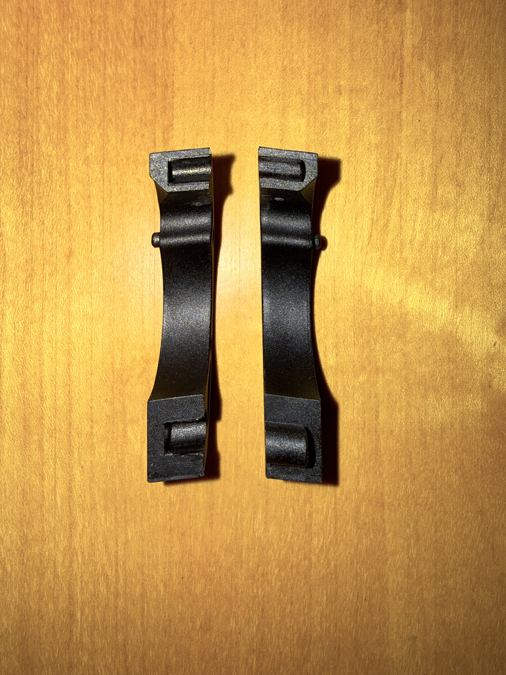
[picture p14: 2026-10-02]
01_Input/2026-09-28_Tavelo-Spacer_Teilung_IMG_8872.jpg

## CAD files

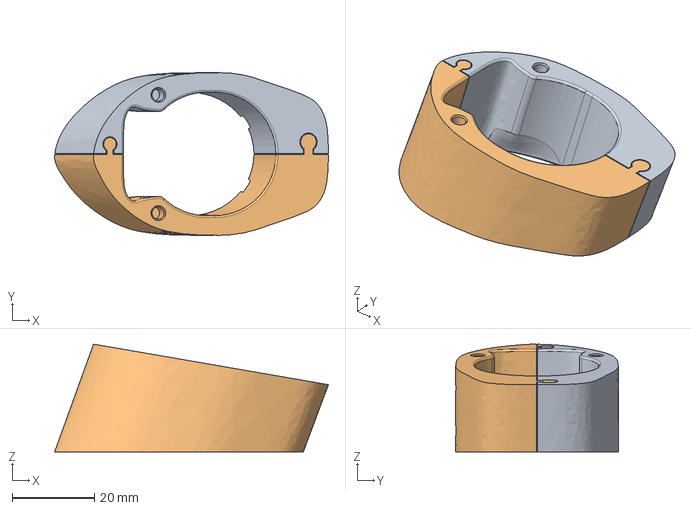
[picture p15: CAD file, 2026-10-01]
02_CAD/out/Adapter_H22_T17_V7.2_Passstift.step
66.7 x 39.6 x 26.2 mm

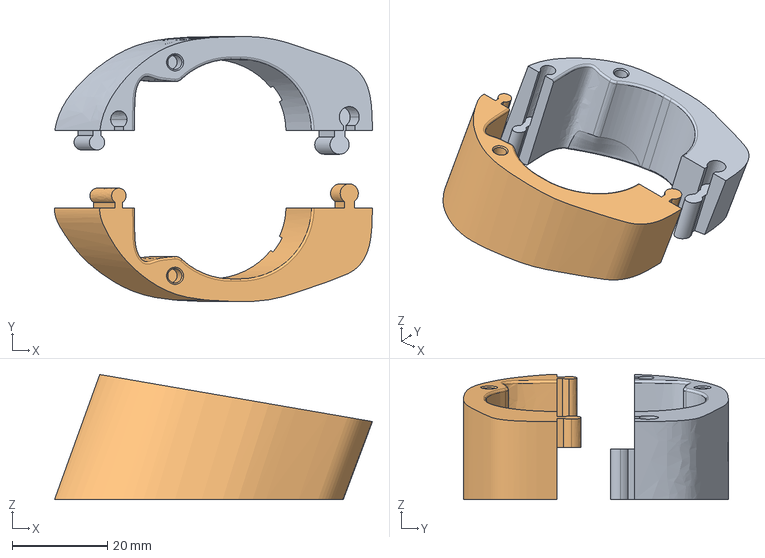
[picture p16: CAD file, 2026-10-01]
02_CAD/out/Passstift/DRUCK_Adapter_H22_T17_V7.2_Passstift.step
66.7 x 55.5 x 26.2 mm

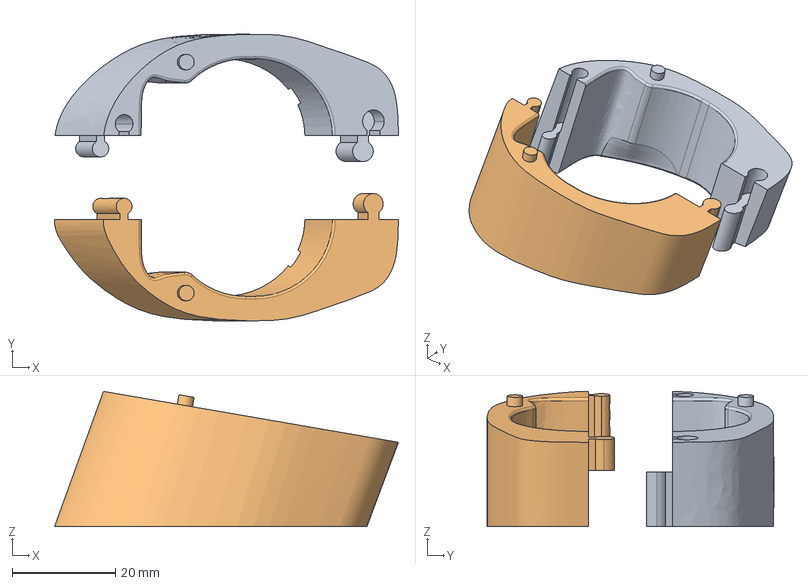
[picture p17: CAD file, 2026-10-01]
02_CAD/out/Stift/DRUCK_Adapter_H22_T17_V7.2_Stift.step
66.7 x 55.5 x 26.2 mm

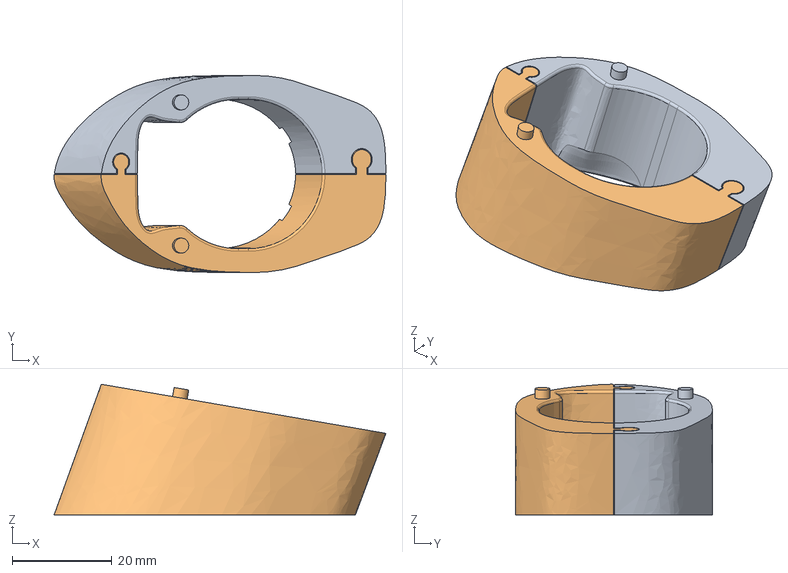
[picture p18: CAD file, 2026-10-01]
02_CAD/out/Stift/Adapter_H22_T17_V7.2_Stift.step
66.7 x 39.6 x 26.2 mm

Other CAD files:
02_CAD/out/DRUCK_Adapter_H22_T17_V7.2_Passstift.step
02_CAD/out/Passstift/Adapter_H22_T17_V7.2_Passstift.step
02_CAD/out/DRUCK_Adapter_H22_T17_V7.2.step
02_CAD/out/Adapter_H22_T17_V7.2.step
02_CAD/out/Passstift/Adapter_H22_T17_V7.2_Passstift.stl
02_CAD/out/Passstift/DRUCK_Adapter_H22_T17_V7.2_Passstift.3mf
02_CAD/out/Passstift/DRUCK_Adapter_H22_T17_V7.2_Passstift.stl
02_CAD/out/Stift/Adapter_H22_T17_V7.2_Stift.stl
02_CAD/out/Stift/DRUCK_Adapter_H22_T17_V7.2_Stift.3mf
02_CAD/out/Stift/DRUCK_Adapter_H22_T17_V7.2_Stift.stl

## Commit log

2026-09-28 Adapter Émonda SL 6 → Tavelo Avro Rise, Rev. B.1
    Parametrisches CadQuery-Modell des zweiteiligen Spacer-Adapters
    (Keil 9°: Trek α_T 17° vorläufig, Tavelo α_V 8° gemessen; Höhe 20 mm
    entlang der Schaftachse; Gelenk nach Tavelo-Vorbild), Druckdateien
    für Adapter und Lehrkeile 15–19°, Renderings, Anforderungen und
    Druckaufträge sowie das verwendete Input-Material.
    Claude-Session: https://claude.ai/code/session_01Hd3qfhqnJobezoX1Y5tUfd
    [Adapter_H20_T17_V8.step, Adapter_H20_T17_V8.stl, DRUCK_Adapter_H20_T17_V8.3mf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]
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2026-09-28 Lehrkeile entfernt
    Die Messkeile (15–19°) werden nicht mehr gebraucht: Der Adapter selbst
    dient als Test für den Trek-Winkel. Entfernt: Druckdateien, Rendering,
    Render-Skript, gauge() im Modell, Doku-Abschnitte. Die Diagnose über die
    untere Fuge (Spalt hinten/vorn) steht jetzt im Montageabschnitt.
    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
    [DRUCK_Lehrkeil_15_0deg.3mf, DRUCK_Lehrkeil_15_0deg.step, DRUCK_Lehrkeil_15_0deg.stl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]
2026-09-29 Anpassungen nach dem ersten Prototyp
    - Taschen für die Trek-Nasen 2,5 tief (vorher 1,8)
    - Unterseite: Spitze 2,5 weiter vorn, Oberseite unverändert
    - Stifte oben 1,5 nach vorn (42,0 statt 40,5 ab Hinterkante),
    der Adapter saß 1,5 zu weit vorn
    - Exporte und Renderings neu erzeugt
    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
    [Adapter_H20_T17_V8.step, Adapter_H20_T17_V8.stl, DRUCK_Adapter_H20_T17_V8.3mf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]
2026-09-29 Bohrung Ø 30 als Langloch, vorderes Gelenk verschoben
    - Bohrung senkrecht zur Schaftachse rund (vorher Kreise parallel zur
    Unterseite, dadurch längs nur 27,6 und enger als der Schaft)
    - Ø 30 statt 28,9, nach hinten um 2 zum Langloch 32 × 30 verlängert,
    Vorderkante fest; die Lage kommt von Nasen und Stiften
    - vorderes Gelenk 0,75 nach vorn (x = −24,85): Wand zum Leitungskanal
    1,05 → 1,8
    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
    [Adapter_H20_T17_V8.step, Adapter_H20_T17_V8.stl, DRUCK_Adapter_H20_T17_V8.3mf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]
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2026-09-29 Feinschliff: Nasentaschen zur Bohrung offen, Kantenradien
    - Nasentaschen am vorderen Ende per Durchbruch in Taschenbreite zur
    Bohrung geöffnet; statt eines 0,27-Stegs stumpfwinklige Übergänge
    - Kantenradien an Ober- und Unterseite: Bohrung R 1,0,
    Leitungskanal R 0,5 (Wand zum vorderen Gelenk bleibt 1,21)
    - innen am Übergang Langloch → Leitungskanal R 2,0
    - check_adapter.py berücksichtigt die Radien
    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
    [Adapter_H20_T17_V8.step, Adapter_H20_T17_V8.stl, DRUCK_Adapter_H20_T17_V8.3mf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]
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2026-10-01 Leitungsschräge an der Unterseite (Rev. C.1)
    - hintere Bremsleitung kommt seitlich rechts aus dem Trek-Deckel:
    beidseitig Bogen R 45 von der äußersten Kanalecke zur breitesten
    Stelle des Langlochs, Material fällt schräg weg, läuft nach 10 mm
    entlang der Achse aus; Oberseite unverändert
    - Kante Unterseite ↔ Schräge R 0,5; Schräge wird vor dem Verrunden
    abgezogen
    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
    [Adapter_H20_T17_V8.step, Adapter_H20_T17_V8.stl, DRUCK_Adapter_H20_T17_V8.3mf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]
2026-10-01 Übergänge an der Leitungsschräge geglättet, Kantenradien einheitlich
    - Rundung Langloch → Kanal (R 2,0) als Teil des Schnitts statt als
    Verrundung; die Leitungsschräge trifft dieselbe Rundung, kein Grat
    - Schräge: untere Hälfte gerade, obere läuft tangential in Kanal- und
    Bohrungswand aus (kein Knick)
    - alle inneren Kanten oben und unten einheitlich R 0,5 (tangentiale
    Kantenzüge lassen sich nur mit einem Radius verrunden); kein Absatz
    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
    [Adapter_H20_T17_V8.step, Adapter_H20_T17_V8.stl, DRUCK_Adapter_H20_T17_V8.3mf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]
2026-10-01 Keilkorrektur nach Prototyp 2 und Höhe 22 (Rev. C.2, C.3)
    - Prototyp 2 (Fühlerlehre, montiert): oben vorn 0,8 Spalt zum Vorbau,
    hinten dicht. Neuer Eingabewert TOP_FRONT_LIFT = 0,8: Oberseite um
    ihre Hinterkante gekippt; daraus α_V 7,21° (gemessen 8°), Keil 9,79°.
    Der Vorbau sitzt dadurch nicht höher, nur der Spalt wird gefüllt
    (nachgerechnet: Lage entlang der Achse +0,0002 mm)
    - Bezugshöhe HEIGHT_REF 20 → 22: Vorbau 2,0 höher, damit die Top-Cap
    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
    [Adapter_H20_T17_V8.step, Adapter_H20_T17_V8.stl, Adapter_H22_T17_V7.2.step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]
2026-10-01 Nasentaschen breiter und tiefer, Doku auf Stand Rev. C.4
    - Nasentaschen: Spiel quer 0,3 → 0,55 pro Seite (Breite 3,5),
    Tiefe 2,5 → 3,0, damit der Adapter leichter bündig auf dem
    Trek-Deckel sitzt; Längsspiel unverändert 0,3
    - KONSTRUKTION.md: Stand Rev. C.4, Befund der Prototypen 1 und 2
    zusammengefasst (inkl. Top-Cap/Höhe), Prüfliste für Prototyp 3
    - README: Stand, Kanten, Montage (Spalt für die Top-Cap, obere Fuge
    über TOP_FRONT_LIFT korrigieren), Taschenparameter
    - CLAUDE.md: Unterseitenkontur nicht ändern, Taschenmaße, Hinweis zur
    Dateiübertragung
    Claude-Session: https:/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
    [Adapter_H22_T17_V7.2.step, Adapter_H22_T17_V7.2.stl, DRUCK_Adapter_H22_T17_V7.2.3mf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]
2026-10-01 Zweite Variante Passstift, Doku auf Stand Rev. C.5
    Zwei Varianten, die sich nur an den Stiften oben unterscheiden und
    denselben Grundkörper teilen: Stift (angedruckt, wie bisher) und
    Passstift (Sacklöcher Ø 3,0 × 7,15 mit Fase 0,3 für eingeklebte
    Zylinderstifte ISO 2338 Ø 3 m6 × 8, Überstand 1,85 wie angedruckt).
    Dazu eine Lehre für den Überstand. Dateinamen mit Variante.
    Prüfskript prüft beide Varianten und die Wand um die Sacklöcher
    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
    [Adapter_H22_T17_V7.2_Passstift.step, Adapter_H22_T17_V7.2_Passstift.stl, Adapter_H22_T17_V7.2_Stift.step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]
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2026-10-02 Rev. D: Stand abgeschlossen, Repo für die Veröffentlichung bereinigt
    Prototyp 3 (Variante Passstift) passt ohne weitere Korrektur; die
    Geometrie bleibt wie C.6 (Exporte und Renderings unverändert).
    - README: Abschnitt „Variante wählen“ mit Vergleich und Bildern,
    Montageanleitung entfernt, Anpassen an andere Räder als eigener
    Abschnitt, Lizenzausnahme für die Herstellerzeichnung
    - KONSTRUKTION: Befund Prototyp 3, Revision D, offene Punkte
    aktualisiert, Wandstärken am vorderen Gelenk korrigiert,
    Anleitungsteile aus D-12 entfernt
    - CLAUDE.md ohne persönliche Arbeitsregeln und lokale Pfade
    - Skripte unabhängig vom Aufrufort, ungenutzte Funktion entfernt,
    getestete Version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
